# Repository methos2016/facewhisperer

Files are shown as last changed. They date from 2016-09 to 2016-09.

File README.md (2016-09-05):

FaceWhisperer
-------------

FaceWhisperer is a hardware add-on for the [ChipWhisperer](https://newae.com/tools/chipwhisperer/) side-channel analysis tool, for working with devices that primarily communicate over USB. The goal is to create a USB host controller scripted with an experiment, all running totally synchronous with the target. This should give predictable timing each time the experiment is run from a target reset.

One proven use for this is to glitch GET_DESCRIPTOR requests into returning firmware images for devices that don't otherwise have firmware available for inspection.

The experiments are scripted from an ATxmega128 processor, same as the one included on ChipWhisperer-Lite. The USB host is a MAX3241E, inspired by Travis Goodspeed's [Facedancer21](http://goodfet.sourceforge.net/hardware/facedancer21/) tool.

For keeping the target device in sync, this board provides a 12 MHz clock output, an open-collector reset output, and a trigger input with adjustable voltage threshold.

This project is a quick hack that builds on the work and inspiration of several great projects:

- [GoodFET](http://goodfet.sourceforge.net)
- [ChipWhisperer](https://newae.com/tools/chipwhisperer)
- [Xmegaduino](https://github.com/Xmegaduino/Xmegaduino)
- [Arduino USB Host Shield library](https://github.com/felis/USB_Host_Shield_2.0)

Hardware Errata
---------------

The current PCB design is usable, but there are some changes that still need to be made before I'd recommend anyone manufacture the design:

- Labels on the silkscreen and copper layers. I was milling the Rev A board, so I kept it simple.
- The CLK output is rather weak. I used the NC7WZ14 because I had them on hand, but they're just barely up to the task.
- I originally included the second CLK SMA jack for clock glitching via the CWLite's crowbar FET, but that's silly and this should really just have an XOR on-board for inserting glitches in the target clock without disrupting the facewhisperer itself.
- The SYNCIN didn't make it into the first board design at all, I had to rework it on.
- I didn't include headers for the spare GPIOs in the first board, for expediency's sake, but these would be an obviously handy addition.
- Connector placement is awkward. Rethink this around optimal coax routing.
- FTDI header for sniffing the serial bus. Jumper for optional transmit. I ended up using an FTDI cable to log the results while also allowing CWLite's serial port to orchestrate the glitching process.
- Maybe use a better transistor for the reset puller. The 2N7000 was just what I had handy. Also maybe take the LED off the gate, it may have been causing some 100ns-scale glitches in the reset's falling edge.
- Lots more test points and posts and things for you to grab onto with a logic analyzer.

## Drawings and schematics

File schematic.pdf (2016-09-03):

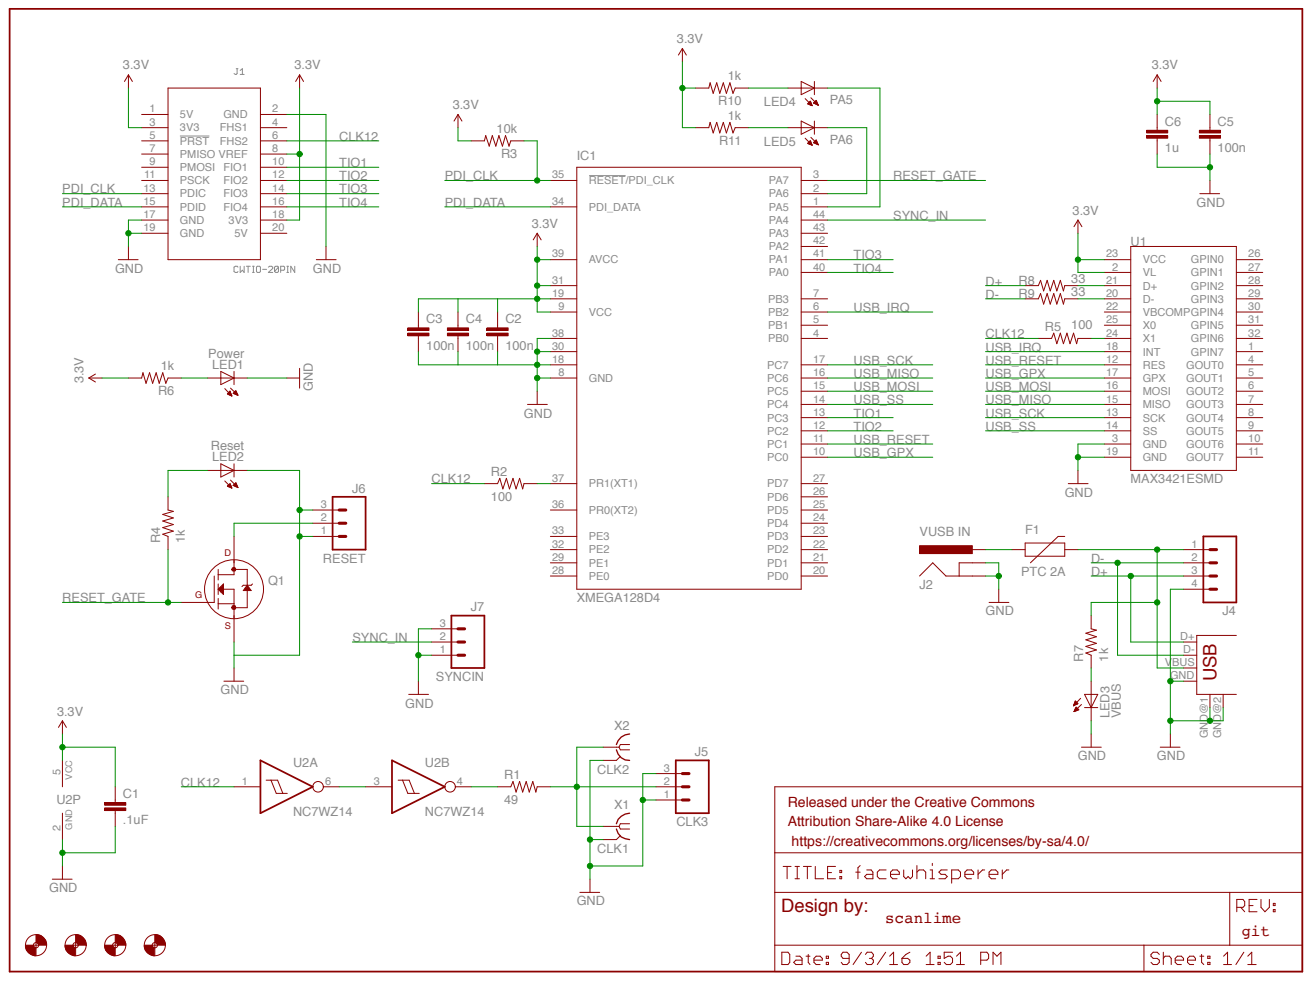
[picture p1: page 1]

D-
VBUS

Released under the Creative Commons
Attribution Share-Alike 4.0 License
https://creativecommons.org/licenses/by-sa/4.0/

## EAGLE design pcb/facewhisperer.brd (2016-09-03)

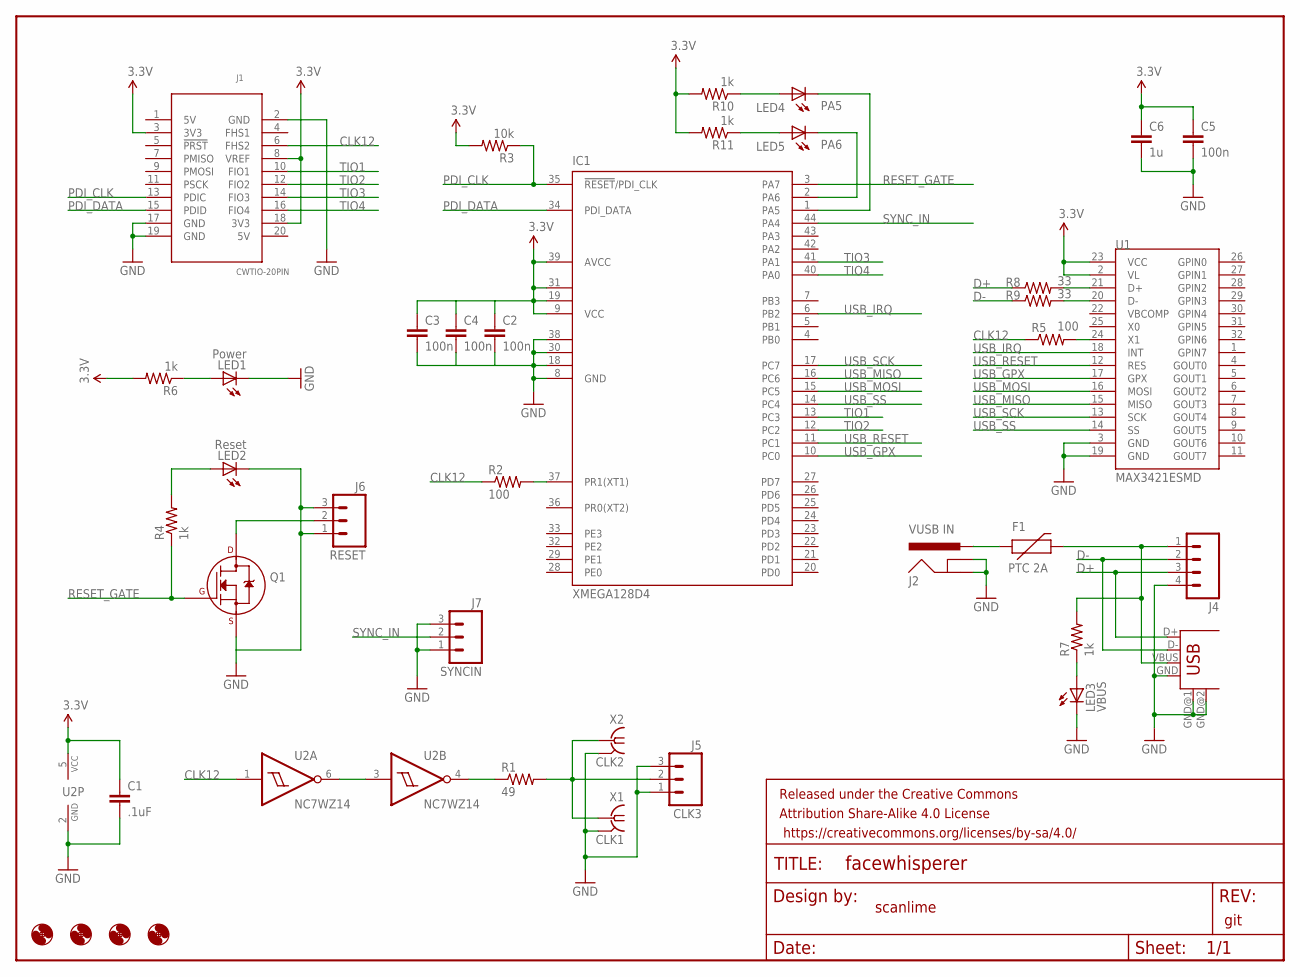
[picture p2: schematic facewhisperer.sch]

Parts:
C1: .1uF; 0805
C2, C3, C4, C5: 100n; 0805
C6: 1u; 0805
F1: PTC 2A; PTC-1206-WIDE
FRAME1: FRAME-LETTERNO_PACKAGE; DUMMY
H1, H2, H3, H4: MOUNT-HOLE3.2; 3,2
IC1: XMEGA128D4; TQFP44
J1: CWTIO-20PIN; PINSHRD_PTH_2X10
J2: VUSB IN; POWER_JACK_PTH
J3: USB-A-H
J4: M04LOCK_LONGPADS; 1X04_LOCK_LONGPADS
J5: CLK3; 1X03_LOCK_LONGPADS
J6: RESET; 1X03_LOCK_LONGPADS
J7: SYNCIN; 1X03_LOCK_LONGPADS
LED1: Power; 1206
LED2: Reset; 1206
LED3: VBUS; 1206
LED4: PA5; 1206
LED5: PA6; 1206
Q1: 2N7002_SOT23; SOT-23
R1: 49; 0805
R2, R5: 100; 0805
R3: 10k; 0805
R4, R6, R7, R10, R11: 1k; 0805
R8, R9: 33; 0805
U1: MAX3421ESMD; TQFP32-5MM-MILLABLE
U2: NC7WZ14; SC70-6-MILLABLE
X1: CLK1; J502-ND-142-0711-821/826-NOSILK
X2: CLK2; J502-ND-142-0711-821/826-NOSILK

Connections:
3.3V: C1.1, C2.1, C3.1, C4.1, C5.1, C6.1, IC1.9 (VCC), IC1.19 (VCC1), IC1.31 (VCC2), IC1.39 (AVCC), J1.3 (3V3), J1.8 (VREF), J1.18 (3V3), R3.2, R6.2, R10.2, R11.2, U1.2 (VL), U1.23 (VCC), U2.5 (VCC)
CLK12: J1.6 (FHS2), R2.1, R5.1, U2.1 (IN)
D+: J3.D+, J4.3, R8.1
D-: J3.D-, J4.2, R9.1
GND: C1.2, C2.2, C3.2, C4.2, C5.2, C6.2, IC1.8 (GND), IC1.18 (GND1), IC1.30 (GND2), IC1.38 (GND3), J1.2 (GND), J1.17 (GND), J1.19 (GND), J2.GND, J2.GNDBREAK, J3.GND, J3.GND@1 (GND), J3.GND@2 (GND), J4.4, J5.1, J5.3, J6.1, J6.3, J7.1, J7.3, LED1.C, LED2.C, LED3.C, Q1.2 (S), U1.3 (GND), U1.19 (GND), U2.2 (GND), X1.G@1 (2), X1.G@2 (2), X1.G@3 (2), X1.G@4 (2), X2.G@1 (2), X2.G@2 (2), X2.G@3 (2), X2.G@4 (2)
unnamed: U2.3 (IN), U2.6 (OUT)
unnamed: R1.1, U2.4 (OUT)
unnamed: J5.2, R1.2, X1.1, X2.1
unnamed: R5.2, U1.24 (X1)
unnamed: F1.2, J3.VBUS, J4.1, R7.2
unnamed: LED2.A, R4.2
unnamed: IC1.37 (PR1(XT1)), R2.2
unnamed: J6.2, Q1.3 (D)
unnamed: LED1.A, R6.1
unnamed: LED3.A, R7.1
unnamed: R9.2, U1.20 (D-)
unnamed: R8.2, U1.21 (D+)
unnamed: F1.1, J2.PWR
unnamed: LED4.A, R10.1
unnamed: LED5.A, R11.1
unnamed: IC1.2 (PA6), LED5.C
unnamed: IC1.1 (PA5), LED4.C
PDI_CLK: IC1.35 (!RESET!/PDI_CLK), J1.13 (PDIC), R3.1
PDI_DATA: IC1.34 (PDI_DATA), J1.15 (PDID)
RESET_GATE: IC1.3 (PA7), Q1.1 (G), R4.1
SYNC_IN: IC1.44 (PA4), J7.2
TIO1: IC1.13 (PC3), J1.10 (FIO1)
TIO2: IC1.12 (PC2), J1.12 (FIO2)
TIO3: IC1.41 (PA1), J1.14 (FIO3)
TIO4: IC1.40 (PA0), J1.16 (FIO4)
USB_GPX: IC1.10 (PC0), U1.17 (GPX)
USB_IRQ: IC1.6 (PB2), U1.18 (INT)
USB_MISO: IC1.16 (PC6), U1.15 (MISO)
USB_MOSI: IC1.15 (PC5), U1.16 (MOSI)
USB_RESET: IC1.11 (PC1), U1.12 (RES)
USB_SCK: IC1.17 (PC7), U1.13 (SCK)
USB_SS: IC1.14 (PC4), U1.14 (SS)

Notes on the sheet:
scanlime
git

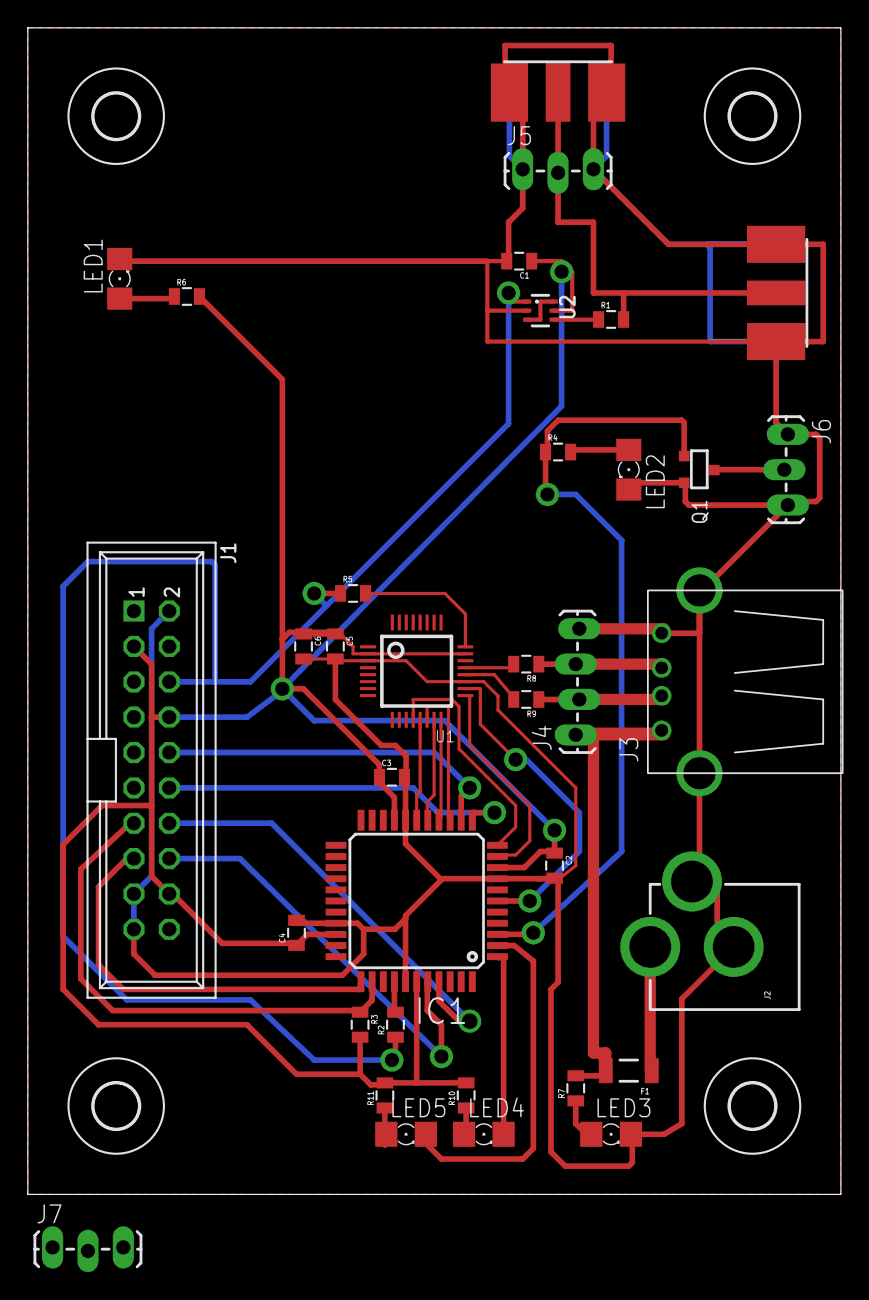
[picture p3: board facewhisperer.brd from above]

Board: 2 copper layers, 58.4 x 83.8 mm, 41 parts (0 on the bottom side), 37 nets.

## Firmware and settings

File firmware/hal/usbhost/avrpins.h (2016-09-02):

/* Copyright (C) 2011 Circuits At Home, LTD. All rights reserved.

This software may be distributed and modified under the terms of the GNU
General Public License version 2 (GPL2) as published by the Free Software
Foundation and appearing in the file GPL2.TXT included in the packaging of
this file. Please note that GPL2 Section 2[b] requires that all works based
on this software must also be made publicly available under the terms of
the GPL2 ("Copyleft").

Contact information
-------------------

Circuits At Home, LTD
Web      :  http://www.circuitsathome.com
e-mail   :  support@circuitsathome.com
 */

/* derived from Konstantin Chizhov's AVR port templates */

#if !defined(_usb_h_) || defined(_avrpins_h_)
#error "Never include avrpins.h directly; include Usb.h instead"
#else
#define _avrpins_h_

#if defined(__AVR_XMEGA__)

// SetDirRead:
//   Disable interrupts
//   Disable the pull up resistor
//   Set to INPUT
//   Enable PIO

// SetDirWrite:
//   Disable interrupts
//   Disable the pull up resistor
//   Set to OUTPUT
//   Enable PIO

#define MAKE_PIN(className, pio, pin) \
class className { \
public: \
  static void Set() { \
    pio.OUTSET = 1 << pin; \
  } \
  static void Clear() { \
    pio.OUTCLR = 1 << pin; \
  } \
  static void SetDirRead() { \
    uint8_t* pinctrl = (uint8_t*)&pio.PIN0CTRL; \
    pio.DIRCLR = 1 << pin; \
    pinctrl[pin] &= ~PORT_OPC_gm; \
  } \
  static void SetDirWrite() { \
    uint8_t* pinctrl = (uint8_t*)&pio.PIN0CTRL; \
    pio.DIRSET = 1 << pin; \
    pinctrl[pin] &= ~PORT_OPC_gm; \
  } \
  static uint8_t IsSet() { \
    return pio.IN & (1 << pin); \
  } \
};

MAKE_PIN(P0,  PORTC, 2);
MAKE_PIN(P1,  PORTC, 3);
MAKE_PIN(P2,  PORTC, 0);
MAKE_PIN(P3,  PORTC, 1);
MAKE_PIN(P4,  PORTD, 2);
MAKE_PIN(P5,  PORTD, 3);
MAKE_PIN(P6,  PORTD, 4);
MAKE_PIN(P7,  PORTB, 2);
MAKE_PIN(P8,  PORTB, 3);
MAKE_PIN(P9,  PORTC, 4);
MAKE_PIN(P10, PORTC, 5);
MAKE_PIN(P11, PORTD, 5);
MAKE_PIN(P12, PORTD, 6);
MAKE_PIN(P13, PORTD, 7);
MAKE_PIN(P14, PORTE, 0);
MAKE_PIN(P15, PORTE, 1);
MAKE_PIN(P16, PORTE, 2);
MAKE_PIN(P17, PORTE, 3);
MAKE_PIN(P18, PORTD, 0);
MAKE_PIN(P19, PORTD, 1);
MAKE_PIN(P20, PORTC, 6);
MAKE_PIN(P21, PORTC, 7);
MAKE_PIN(P22, PORTA, 1);
MAKE_PIN(P23, PORTA, 2);
MAKE_PIN(P24, PORTA, 3);
MAKE_PIN(P25, PORTA, 4);
MAKE_PIN(P26, PORTA, 5);
MAKE_PIN(P27, PORTA, 6);
// XMEGA, Akafuino variant

#elif defined(__AVR__)

// pointers are 16 bits on AVR
#define pgm_read_pointer(p) pgm_read_word(p)

// Support for these boards needs to be manually activated in settings.h or in a makefile
#if !defined(BOARD_MEGA_ADK) && defined(__AVR_ATmega2560__) && (USE_UHS_MEGA_ADK || defined(ARDUINO_AVR_ADK))
#define BOARD_MEGA_ADK
#elif !defined(BOARD_BLACK_WIDDOW) && USE_UHS_BLACK_WIDDOW
#define BOARD_BLACK_WIDDOW
#endif

#ifdef PORTA
#define USE_PORTA
#endif
#ifdef PORTB
#define USE_PORTB
#endif
#ifdef PORTC
#define USE_PORTC
#endif
#ifdef PORTD
#define USE_PORTD
#endif
#ifdef PORTE
#define USE_PORTE
#endif
#ifdef PORTF
#define USE_PORTF
#endif
#ifdef PORTG
#define USE_PORTG
#endif
#ifdef PORTH
#define USE_PORTH
#endif
#ifdef PORTJ
#define USE_PORTJ
#endif
#ifdef PORTK
#define USE_PORTK
#endif
#ifdef PORTL
#define USE_PORTL
#endif
#ifdef PORTQ
#define USE_PORTQ
#endif
#ifdef PORTR
#define USE_PORTR
#endif

#ifdef TCCR0A
#define USE_TCCR0A
#endif
#ifdef TCCR1A
#define USE_TCCR1A
#endif
#ifdef TCCR2A
#define USE_TCCR2A
#endif

//Port definitions for AtTiny, AtMega families.

#define MAKE_PORT(portName, ddrName, pinName, className, ID) \
    class className{\
    public:\
      typedef uint8_t DataT;\
    public:\
      static void Write(DataT value){portName = value;}\
      static void ClearAndSet(DataT clearMask, DataT value){portName = (portName & ~clearMask) | value;}\
      static DataT Read(){return portName;}\
      static void DirWrite(DataT value){ddrName = value;}\
      static DataT DirRead(){return ddrName;}\
      static void Set(DataT value){portName |= value;}\
      static void Clear(DataT value){portName &= ~value;}\
      static void Toggle(DataT value){portName ^= value;}\
      static void DirSet(DataT value){ddrName |= value;}\
      static void DirClear(DataT value){ddrName &= ~value;}\
      static void DirToggle(DataT value){ddrName ^= value;}\
      static DataT PinRead(){return pinName;}\
      enum{Id = ID};\
      enum{Width=sizeof(DataT)*8};\
    };

// TCCR registers to set/clear Arduino PWM
#define MAKE_TCCR(TccrName, className) \
    class className{\
    public:\
      typedef uint8_t DataT;\
    public:\
      static void Write(DataT value){TccrName = value;}\
      static void ClearAndSet(DataT clearMask, DataT value){TccrName = (TccrName & ~clearMask) | value;}\
      static DataT Read(){return TccrName;}\
      static void Set(DataT value){TccrName |= value;}\
      static void Clear(DataT value){TccrName &= ~value;}\
      static void Toggle(DataT value){TccrName ^= value;}\
      enum{Width=sizeof(DataT)*8};\
    };

#ifdef USE_PORTA
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

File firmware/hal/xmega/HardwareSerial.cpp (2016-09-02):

/*
  HardwareSerial.cpp - Hardware serial library for Wiring
  Copyright (c) 2006 Nicholas Zambetti.  All right reserved.

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
  Modified 23 November 2006 by David A. Mellis
*/

#include <stdlib.h>
#include <stdio.h>
#include <string.h>
#include <inttypes.h>
#include "Arduino.h"
#include "wiring_private.h"

#include "HardwareSerial.h"

// Define constants and variables for buffering incoming serial data.  We're
// using a ring buffer (I think), in which rx_buffer_head is the index of the
// location to which to write the next incoming character and rx_buffer_tail
// is the index of the location from which to read.
#define RX_BUFFER_SIZE 180

struct ring_buffer
{
  unsigned char buffer[RX_BUFFER_SIZE];
  int head;
  int tail;
};

inline void store_char(unsigned char c, ring_buffer *rx_buffer)
{
  int i = (unsigned int)(rx_buffer->head + 1) % RX_BUFFER_SIZE;

  // if we should be storing the received character into the location
  // just before the tail (meaning that the head would advance to the
  // current location of the tail), we're about to overflow the buffer
  // and so we don't write the character or advance the head.
  if (i != rx_buffer->tail) {
    rx_buffer->buffer[rx_buffer->head] = c;
    rx_buffer->head = i;
  }
}

// Constructors ////////////////////////////////////////////////////////////////

HardwareSerial::HardwareSerial(
  ring_buffer *rx_buffer,
  USART_t     *usart,
  PORT_t      *port,
  uint8_t      in_bm,
  uint8_t      out_bm)
{
  this->_rx_buffer = rx_buffer;
  this->_usart     = usart;
  this->_port      = port;
  this->_in_bm     = in_bm;
  this->_out_bm    = out_bm;
}

// Public Methods //////////////////////////////////////////////////////////////

void HardwareSerial::begin(unsigned long baud)
{
  uint16_t baud_setting;
  uint8_t bscale = 0;
  uint32_t div1k;
  bool use_u2x;

  // TODO: Serial. Fix serial double clock.
  use_u2x = false;

  _port->DIRCLR = _in_bm;  // input
  _port->OUTSET = _out_bm; // set output high
  _port->DIRSET = _out_bm; // set to output

  // Reset flags
  _usart->CTRLB = 0;

  // set the baud rate
  if (baud > (F_CPU/(use_u2x ? 16 : 32))) return; // Baudrate is set too high

  div1k = ((F_CPU*(use_u2x ? 128UL : 64UL)) / baud) - 1024;
  while ((div1k < 2096640UL) && (bscale < 7)) {
    bscale++;
    div1k <<= 1;
  }

  baud_setting = div1k >> 10;

  _usart->BAUDCTRLA = baud_setting&0xff;
  _usart->BAUDCTRLB = (baud_setting>>8) | ((16-bscale) << 4);

  if(use_u2x)
	_usart->CTRLB |= USART_CLK2X_bm;
  
  // enable Rx and Tx
  _usart->CTRLB |= USART_RXEN_bm | USART_TXEN_bm;
  // enable interrupt
  _usart->CTRLA = (_usart->CTRLA & ~USART_RXCINTLVL_gm) | USART_RXCINTLVL_LO_gc;

  // Char size, parity and stop bits: 8N1
  _usart->CTRLC = USART_CHSIZE_8BIT_gc | USART_PMODE_DISABLED_gc;
}

void HardwareSerial::begin(unsigned long baud, byte config)
{
  begin(baud);

  // Set char size, parity and stop bits
  _usart->CTRLC = config;
}

void HardwareSerial::end()
{
  // disable Rx and Tx
  _usart->CTRLB &= ~(USART_RXEN_bm | USART_TXEN_bm);
  // disable interrupt
  _usart->CTRLA = (_usart->CTRLA & ~USART_RXCINTLVL_gm) | USART_RXCINTLVL_LO_gc;
}

int HardwareSerial::available(void)
{
  return (unsigned int)(RX_BUFFER_SIZE + _rx_buffer->head - _rx_buffer->tail) % RX_BUFFER_SIZE;
}

int HardwareSerial::peek(void)
{
  if (_rx_buffer->head == _rx_buffer->tail) {
    return -1;
  } else {
    return _rx_buffer->buffer[_rx_buffer->tail];
  }
}

int HardwareSerial::read(void)
{
  // if the head isn't ahead of the tail, we don't have any characters
  if (_rx_buffer->head == _rx_buffer->tail) {
    return -1;
  } else {
    unsigned char c = _rx_buffer->buffer[_rx_buffer->tail];
    _rx_buffer->tail = (unsigned int)(_rx_buffer->tail + 1) % RX_BUFFER_SIZE;
    return c;
  }
}

void HardwareSerial::flush()
{
  // don't reverse this or there may be problems if the RX interrupt
  // occurs after reading the value of rx_buffer_head but before writing
  // the value to rx_buffer_tail; the previous value of rx_buffer_head
  // may be written to rx_buffer_tail, making it appear as if the buffer
  // don't reverse this or there may be problems if the RX interrupt
  // occurs after reading the value of rx_buffer_head but before writing
  // the value to rx_buffer_tail; the previous value of rx_buffer_head
  // may be written to rx_buffer_tail, making it appear as if the buffer
  // were full, not empty.
  _rx_buffer->head = _rx_buffer->tail;
}

size_t HardwareSerial::write(uint8_t c)
{
	_usart->DATA = c;
	if ( !(_usart->STATUS & USART_DREIF_bm) )
		while(!(_usart->STATUS & USART_TXCIF_bm));
	_usart->STATUS|=USART_TXCIF_bm;
	
	
  
	return 1;
}

void HardwareSerial::setIREnabled(bool enable)
{
	if(enable)
	{
		_usart->CTRLC |= USART_CMODE_IRDA_gc;
	}
	else
	{
		_usart->CTRLC &= ~USART_CMODE_IRDA_gc;
	}
}

HardwareSerial::operator bool() {
  return true;
}
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

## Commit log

2016-09-01 This will be open, but probably not MIT
    The hardware license is TBD; software is probably going to be GPL because it's based on the Arduino lib.
2016-09-01 Starting an Eagle design
    [facewhisperer.brd, facewhisperer.sch]
2016-09-02 First rev of the PCB design
    [facewhisperer.brd, facewhisperer.sch]
2016-09-02 Rev A
    [facewhisperer.sch]
2016-09-02 Add a PDF schematic for Rev A
2016-09-02 Let's base the firmware on ChipWhisperer's framework
2016-09-02 Local fork of the Arduino USB_Host_Shield_2.0
    Copied from:
    https://github.com/felis/USB_Host_Shield_2.0
    This is after one aborted attempt to make this build as a git submodule.
    For now, it seems better to hack this up locally and avoid pulling in
    much Arduino fluff.
2016-09-02 Include parts of Xmegaduino core
    Rather than gut the arduino support from the USB host library,
    I'm including a minimal subset of Xmegaduino so that the
    mods to usbhost can stay minimal.
2016-09-02 Build fixes for Arduino-style serial port
    [HardwareSerial.cpp, usb-descriptor-simple.cpp]
2016-09-03 SPI fixes
2016-09-03 Reset USB and the local state each time
    [usb-descriptor-simple.cpp, xmega_hal.c]
2016-09-03 Add a sync input for use with analog comparator
    [facewhisperer.brd, facewhisperer.sch]
2016-09-04 Non-RTC timer module with later synchronization
2016-09-04 Fix false sync while reset is still in progress
    [usb-descriptor-simple.cpp]
2016-09-04 Latest settings for homing in on GET_DESCRIPTOR
2016-09-04 Starting Glitch Explorer integration
    [usb-descriptor-simple.cpp]
2016-09-05 Better response filter
2016-09-05 New streaming IN to avoid filling up RAM
    [usb-descriptor-simple.cpp]

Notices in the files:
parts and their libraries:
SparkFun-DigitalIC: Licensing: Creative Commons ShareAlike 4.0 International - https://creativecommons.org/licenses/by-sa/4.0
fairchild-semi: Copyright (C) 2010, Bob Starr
